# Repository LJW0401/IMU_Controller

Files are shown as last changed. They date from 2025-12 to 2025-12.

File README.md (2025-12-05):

# IMU_Controller

（整活系列）用IMU实现的一个简单的体感控制器。

## 设备拓扑关系

连线拓扑关系图

本控制器主要由4部分构成：

1. 机器人信号接收器（Receiver），其WIFI为AP模式，作为主机。
2. 姿态追踪器（Pose Tracker），作为从机，WIFI设置为STA模式，连接至Receiver实现并网，并发送udp数据包。
3. 头部追踪器（Head Tracker），作为从机，WIFI设置为STA模式，连接至Receiver实现并网，并发送udp数据包。
4. 图传模块（Video Transmission），使用DroidCam软件推流，将手机作为天空端，另一台手机连到同一局域网下通过浏览器查看视频流做为一个简单的图传模块，只需3d打印一个眼镜即可。

当`姿态追踪器`和`头部追踪器`都没有连接至`信号接收器`时，发送给机器人的控制信号的设备标识符设置为 `0xFF`。

## 参考成本

|名称|单价|数量|总价|参考链接|
|-|-|-|-|-|
|达妙IMU模块|49|2|98|-|
|TJA1051T模块|5|2|10|-|
|ESP32|24|3|72|-|
|5V电源模块|38|2|76|-|
|键轴模块|10.5|2|21|-|
|合计|=|=|277|=|

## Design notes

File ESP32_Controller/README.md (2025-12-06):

# 追踪器（Tracker）

姿态追踪器和头部追踪器的代码，由于两者代码相似度极高，便集合一起公用一套代码，通过不同的设备ID进行区分，仅做数据采集的功能，具体的数据解析集中由Receiver处理。

## 配置

WIFI模式配置为STA模式，搜寻并连接至接收器网络。

- 名称：`RobotCmd_AP`
- 密码：`12345678`

具体的WIFI通信协议可在 `lib/protocol` 中查看。

`pin 4` 和 `pin 5` 配置为CAN通信引脚，接入CAN网络实现和IMU之间的通信。（也可接入其他CAN设备使用）

IMU选用的是达妙的IMU，非常便宜实惠，可以通过CAN总线快速实现通信。

- 本项目开发时使用的IMU固件版本为1.0.2.4，如为早期版本无法实现通信（因为通信协议有过更新）
- 严格设定 Head Tracker 的 IMU can id 为 0x01 ，Pos Tracker 的 IMU can id 为 0x02 ，本项目依赖IMU id区分不同的 Tracker 数据。

CAN芯片使用的是 JTA1051T，简单方便使用。

## 备注

- 烧录代码时注意选择 main.cpp 中的 tracker_mode。
  
- 在做这个项目时，卡住最久的是达妙IMU的文档更新滞后，文档例程中提供的是和旧版固件的通信，和新固件并不适配。最后在各种排查、找资料才发现这个问题。

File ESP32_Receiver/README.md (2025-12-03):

# 机器人接收器（Receiver）

## 配置

WIFI模式配置为AP模式

- 名称：`RobotCmd_AP`
- 密码：`12345678`
- 监听端口：`3333`

`pin 12` 和 `pin 13` 配置为串口引脚，用来发送SBUS控制指令。（也可拓展为传统UART通信）

## 备注

- 在 `2025.12.3` 的测试时发现发送出去的SBUS信号会有较大概率出现乱码，最后排查出来是 FreeRTOS 的多任务工作造成的，预算非常草率的将所有工作集成到一个任务中进行（还好计算量不是很大）。有空的话可以看看具体原因。

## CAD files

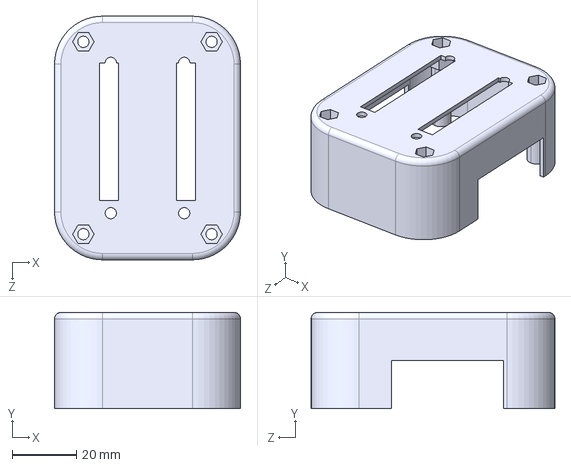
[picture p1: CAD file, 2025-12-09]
Models/Pose/手柄盖子.STEP
58.0 x 30.0 x 76.0 mm

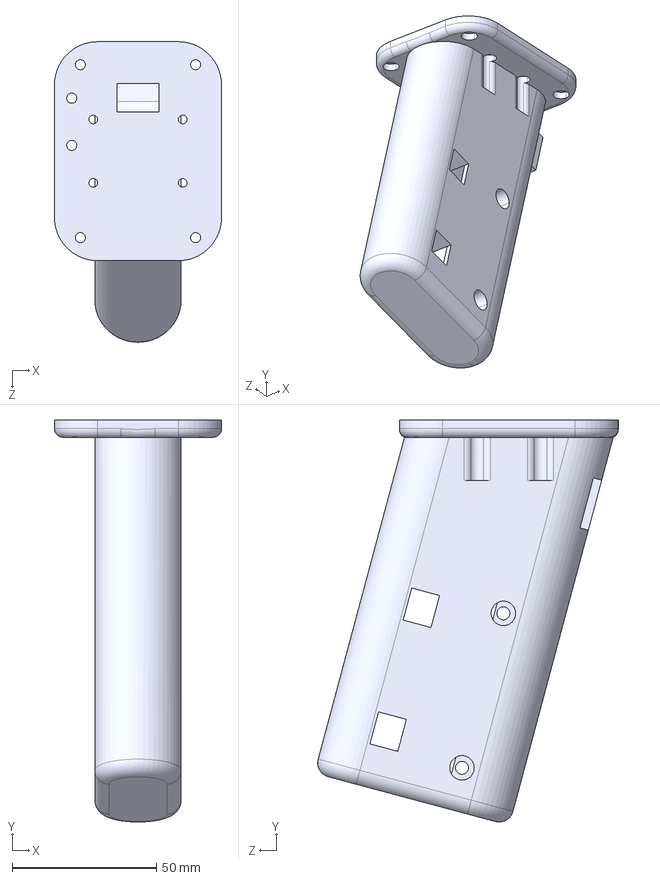
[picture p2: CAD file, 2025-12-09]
Models/Pose/手柄主体.STEP
58.0 x 139.5 x 104.3 mm

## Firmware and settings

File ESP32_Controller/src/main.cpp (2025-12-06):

#include <Arduino.h>

#include "task_imu.hpp"
#include "task_trigger.hpp"
#include "task_upload.hpp"

#define MODE_HEAD_TRACKER 1
#define MODE_POSE_TRACKER 2

// 定义任务句柄
TaskHandle_t ImuTaskHandle = NULL;
TaskHandle_t UploadTaskHandle = NULL;
TaskHandle_t TriggerTaskHandle = NULL;

uint32_t count = 0;

// 设置工作模式
uint32_t tracker_mode = MODE_POSE_TRACKER;

void setup()
{
    Serial.begin(9600);
    delay(100);
    Serial.println();

    // 创建任务
    uint8_t can_id = 0x01;
    uint8_t mst_id = 0x51;
    if (tracker_mode == MODE_HEAD_TRACKER) {
        Serial.println("工作模式: HEAD TRACKER");
        can_id = 0x01;
        mst_id = 0x51;
    } else if (tracker_mode == MODE_POSE_TRACKER) {
        Serial.println("工作模式: POSE TRACKER");
        can_id = 0x02;
        mst_id = 0x52;
    }

    auto * imuParams = new task_imu::ImuParams{can_id, mst_id};
    xTaskCreate(
        task_imu::ImuTask,  // 任务函数
        "ImuTask",          // 任务名称
        4096,               // 任务栈大小（字节）
        imuParams,          // 任务参数
        1,                  // 任务优先级
        &ImuTaskHandle      // 任务句柄
    );

    if (tracker_mode == MODE_POSE_TRACKER) {
        xTaskCreate(
            task_trigger::TriggerTask,  // 任务函数
            "TriggerTask",              // 任务名称
            4096,                       // 任务栈大小（字节）
            NULL,                       // 任务参数
            1,                          // 任务优先级
            &TriggerTaskHandle          // 任务句柄
        );
    }

    xTaskCreate(
        task_upload::UploadTask,  // 任务函数
        "UploadTask",             // 任务名称
        4096,                     // 任务栈大小（字节）
        NULL,                     // 任务参数
        1,                        // 任务优先级
        &UploadTaskHandle         // 任务句柄
    );

    Serial.println("初始化完成");
}

void loop() {}

// END =====================================================

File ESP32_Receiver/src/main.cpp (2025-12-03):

#include <Arduino.h>

#include "task_host.hpp"

using namespace task_host;

// 定义任务句柄
TaskHandle_t HostTaskHandle = NULL;
TaskHandle_t StateControlTaskHandle = NULL;

uint32_t count = 0;

void setup()
{
    Serial.begin(9600);
    delay(100);

    // 创建任务
    xTaskCreate(
        HostTask,        // 任务函数
        "HostTask",      // 任务名称
        4096,            // 任务栈大小（字节）
        NULL,            // 任务参数
        1,               // 任务优先级
        &HostTaskHandle  // 任务句柄
    );


    Serial.println("初始化完成");
}

void loop() {}

// END =====================================================

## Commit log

2025-11-29 🎉 init(all): init
2025-11-29 🎉 init(receiver): init
2025-11-29 创建AP热点
2025-11-29 连接AP热点并发送模拟数据
2025-11-29 添加参考成本
2025-12-02 添加达妙imu的函数库
2025-12-02 获取imu数据
2025-12-02 优化任务周期
2025-12-02 将wifi参数集中到一个文件中方便使用
2025-12-02 将udp发送的函数集成
    方便其他任务中使用udp转发数据
2025-12-02 优化任务分工
    在imu任务中转发数据，wifi任务仅保障通信连接
2025-12-02 将协议部分写成lib，方便项目之间复用
2025-12-02 接收端添加wifi通信协议
2025-12-02 添加了一些重连时的信息
    但好像没什么效果
2025-12-02 试一下数据解码
2025-12-02 修改imu任务周期
2025-12-02 优化一下解码
2025-12-02 添加sbus库
2025-12-02 把imu_data移出来，方便extern
2025-12-02 添加了一些掉线判断
2025-12-02 添加控制部分的处理
2025-12-02 创建控制任务
2025-12-03 优化共享数据模式
2025-12-03 整合Setup和Loop函数
2025-12-03 删除了state control任务
2025-12-03 删除shared
2025-12-03 优化文件格式
2025-12-03 拆分loop
2025-12-03 添加头追imu数据
2025-12-03 添加标识符的设置
2025-12-03 删除多余文件
2025-12-05 添加图传模块
2025-12-06 添加了任务参数传递
    可以在main中控制tracker的类型给不同任务传递不同参数
2025-12-06 添加了扳机检测任务
2025-12-06 更改命名空间的使用
2025-12-06 更新wifi协议
2025-12-06 添加了数据上传
2025-12-06 添加了trigger的解码
2025-12-06 降低了imu任务频率
2025-12-06 添加其他通道的数据
2025-12-06 添加了一些调试数据
2025-12-06 fix 修复了判断条件中使用单等号的问题
2025-12-06 添加了一些参数的展示
2025-12-06 更新文档
2025-12-09 添加了体感控制器的模型
    [手柄主体.STEP, 手柄盖子.STEP]
